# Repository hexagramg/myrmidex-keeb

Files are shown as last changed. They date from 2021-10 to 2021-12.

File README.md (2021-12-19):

# myrmidex-keeb
Myrmidex is split ergo hotswappable keyboard with two rotary encoders. 
Supports controllers with Pro-Micro layout, has footprints for power switch and battery. 

Myrmidex keyboard

In this repository you will find gerbers and schematics. Gerbers were exported with jlcpcb support in mind. Schematics were made in kicad. 

Right now qmk support is implemented, you can find it [here](https://github.com/hexagramg/qmk_firmware/tree/myrmidex/keyboards/myrmidex)

To build this keyboard you will need:
- SOD323 diodes of your choice x50
- PJ 320A trrs x2
- 0805 10k resistors x8
- 0805 10nf capacitors x4
- Kailh hotswap CPG151101S11 x48
- Alps ec11 encoders x2
- 48 mx compatible switches of your choice
- Pro-Micro x2
- Trrs cable

There are places for m2 standoffs, I used these:
- m2 4mm male-female standoff x16 (3mm is possible to fit) https://aliexpress.ru/item/4001271908929.html This one goes between pcb and bottom plate
- m2 3mm female-female standoff x16 https://aliexpress.ru/item/4001271908929.html This one between pcb and top plate
- m2 low profile screws x32 https://aliexpress.ru/item/32981714992.html Screw them tight on the bottom plate and somewhat loose on the top. 

Be careful on soldering left side, one diode on the bottom row is flipped. I will probably correct this in the next version, if there will be one.

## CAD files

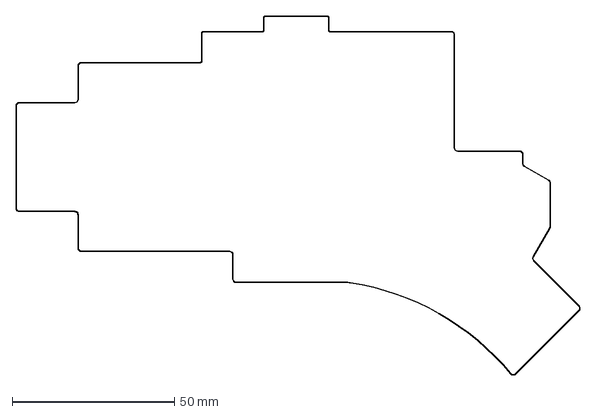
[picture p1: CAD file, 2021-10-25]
sketches/TopPlateEdge.dxf
173.5 x 110.4 mm

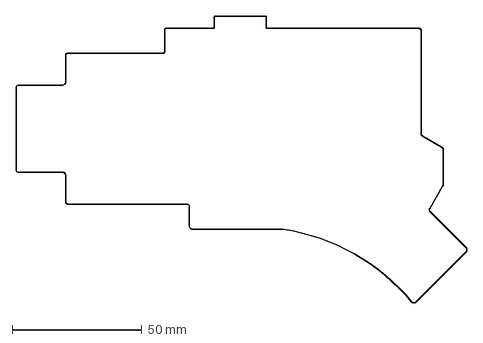
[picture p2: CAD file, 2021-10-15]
sketches/Pcbedge.dxf
173.5 x 110.4 mm

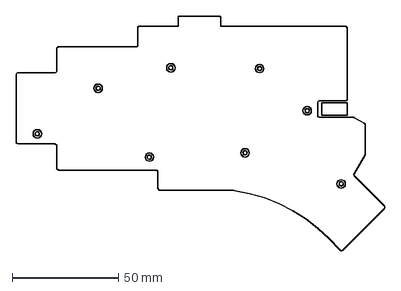
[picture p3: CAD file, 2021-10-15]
sketches/BottomPlateSketch.dxf
173.5 x 110.4 mm

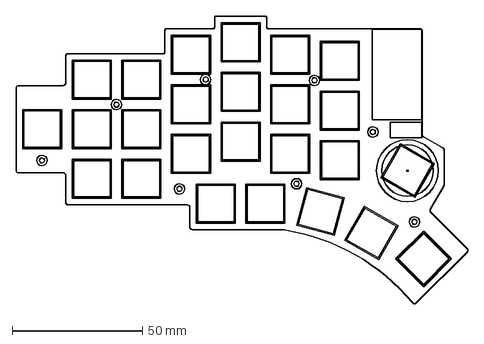
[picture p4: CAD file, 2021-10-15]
sketches/PcbSketch.dxf
173.5 x 110.4 mm

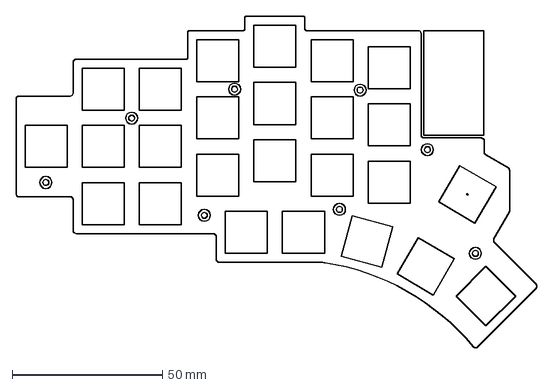
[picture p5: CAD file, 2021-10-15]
sketches/TopPlateSketch.dxf
173.5 x 110.4 mm

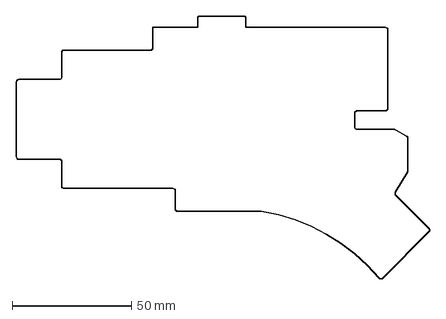
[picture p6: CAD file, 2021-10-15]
sketches/BottomPlateEdge.dxf
173.5 x 110.4 mm

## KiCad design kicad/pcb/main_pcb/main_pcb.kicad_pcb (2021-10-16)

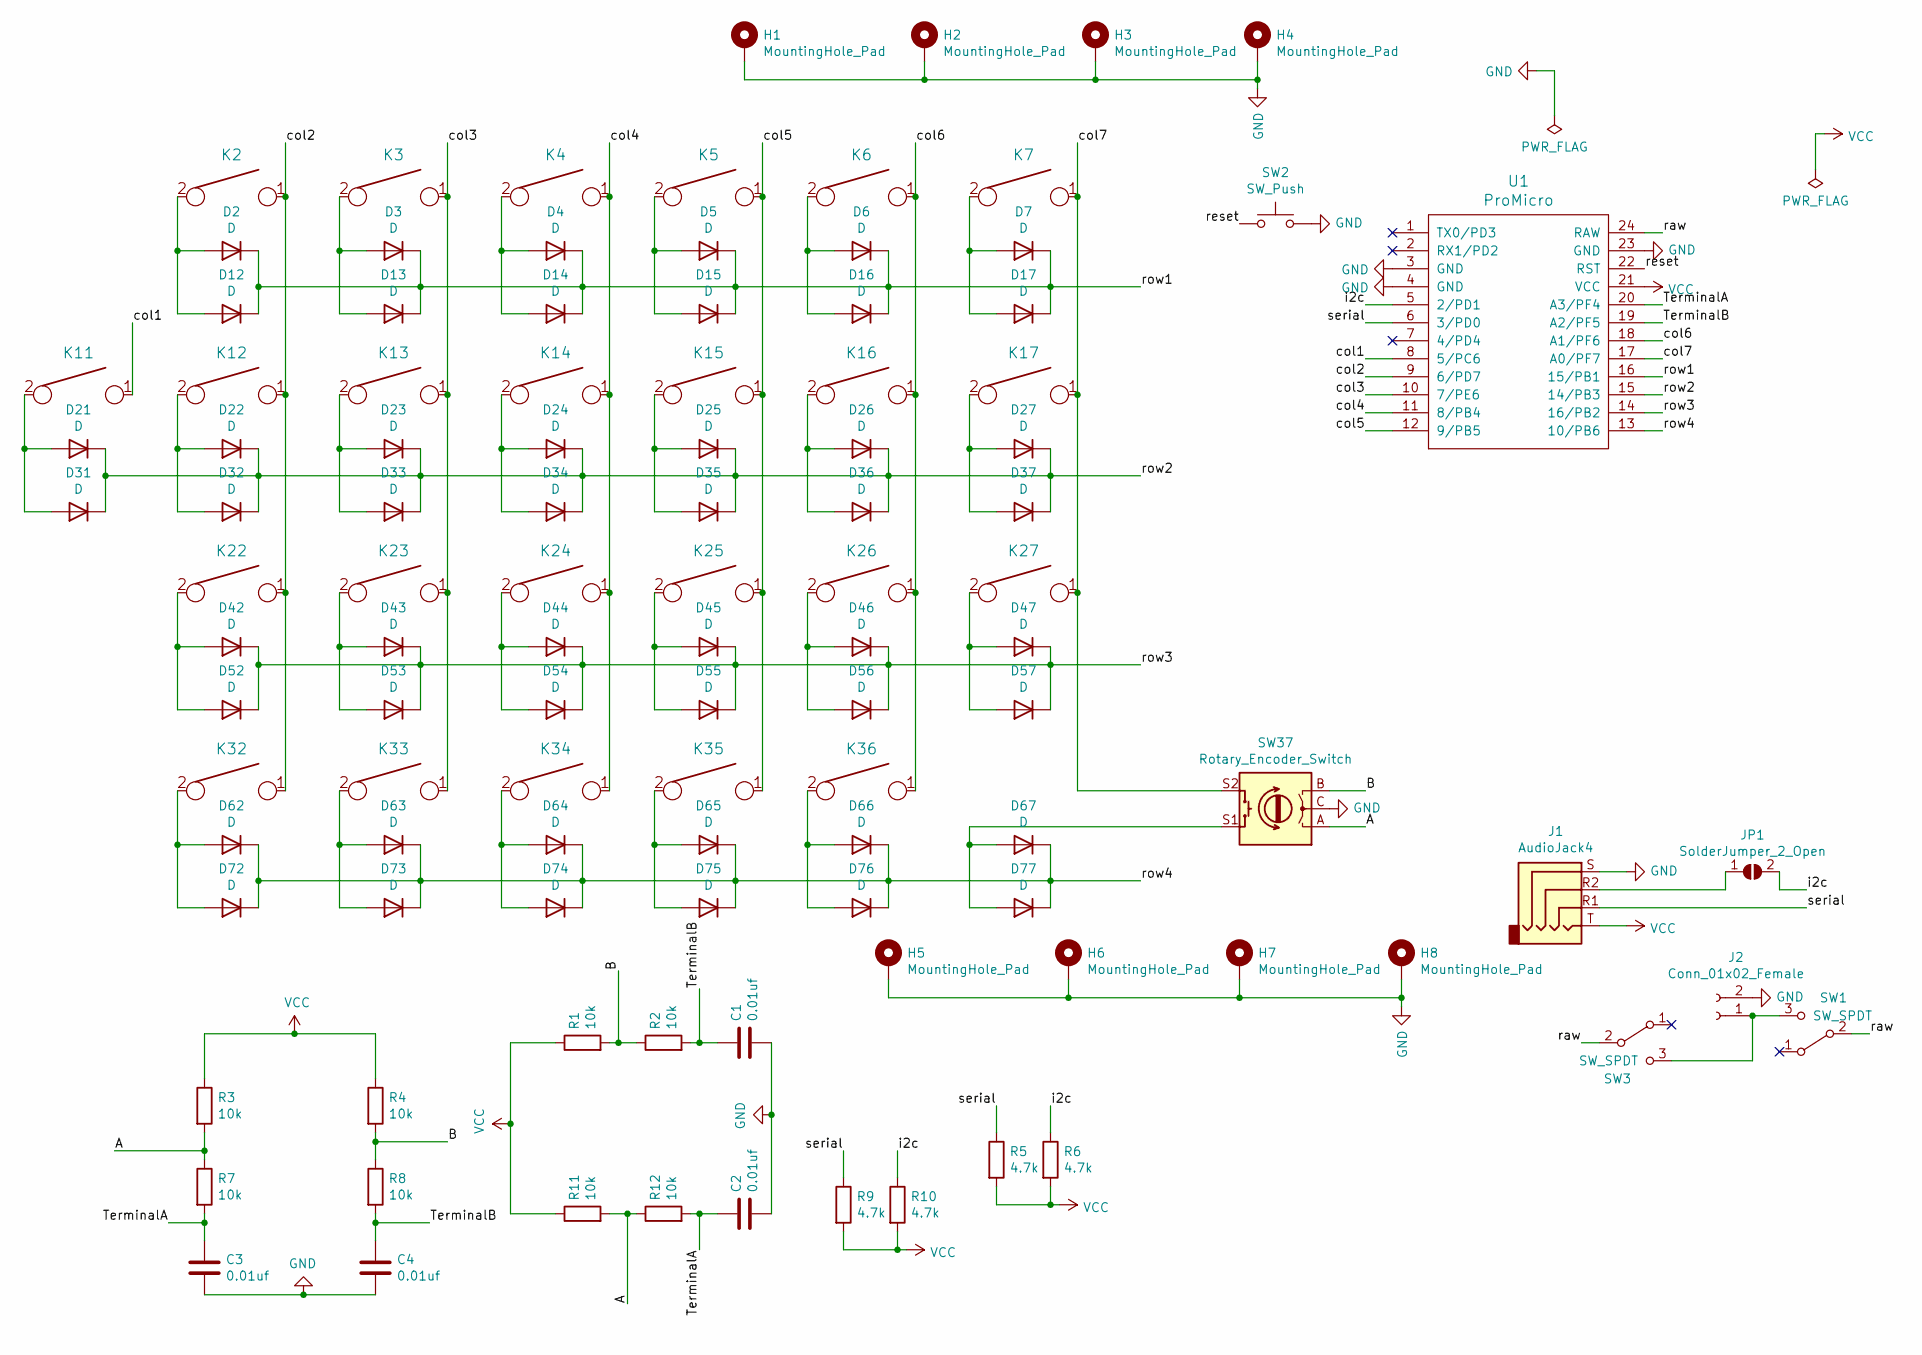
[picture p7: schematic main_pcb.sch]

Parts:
C1, C2, C3, C4: 0.01uf; C_0805_2012Metric_Pad1.18x1.45mm_HandSolder
D2, D3, D4, D5, D6, D7, D12, D13, D14, D15, D16, D17, D21, D22, D23, D24, D25, D26, D27, D31, D32, D33, D34, D35, D36, D37, D42, D43, D44, D45, D46, D47, D52, D53, D54, D55, D56, D57, D62, D63, D64, D65, D66, D67, D72, D73, D74, D75, D76, D77: D; D_0805_2012Metric_Pad1.15x1.40mm_HandSolder
H1, H2, H3, H4, H5, H6, H7, H8: MountingHole_Pad; MountingHole_2.2mm_M2_ISO14580_Pad
J1: AudioJack4; TRRS_PJ-320A_double
J2: Conn_01x02_Female; PinSocket_1x02_P2.54mm_Vertical
JP1: SolderJumper_2_Open; SolderJumper-2_P1.3mm_Open_Pad1.0x1.5mm
K2, K3, K4, K5, K6, K7, K11, K12, K13, K14, K15, K16, K17, K22, K23, K24, K25, K26, K27, K32, K33, K34, K35, K36: KEYSW-keyboard_parts; Kailh_socket_MX_optional_reversible_with_holes
R1, R2, R3, R4, R7, R8, R11, R12: 10k; R_0805_2012Metric_Pad1.20x1.40mm_HandSolder
R5, R6, R9, R10: 4.7k; R_0805_2012Metric_Pad1.20x1.40mm_HandSolder
SW1, SW3: SW_SPDT; SW_SPDT+H-MSK12C01_hor(7pin_SMD)
SW2: SW_Push; Switch_Reset_THT
SW37: Rotary_Encoder_Switch; RotaryEncoder_Alps_EC11E-Switch_Vertical_H20mm
U1: ProMicro; ProMicro_Dual

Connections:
/A: R3.2, R7.1, R11.2, R12.1, SW37.A
/B: R1.2, R2.1, R4.2, R8.1, SW37.B
/TerminalA: C2.1, C3.1, R7.2, R12.2, U1.20 (A3/PF4)
/TerminalB: C1.1, C4.1, R2.2, R8.2, U1.19 (A2/PF5)
/col1: K11.1, U1.8 (5/PC6)
/col2: K2.1, K12.1, K22.1, K32.1, U1.9 (6/PD7)
/col3: K3.1, K13.1, K23.1, K33.1, U1.10 (7/PE6)
/col4: K4.1, K14.1, K24.1, K34.1, U1.11 (8/PB4)
/col5: K5.1, K15.1, K25.1, K35.1, U1.12 (9/PB5)
/col6: K6.1, K16.1, K26.1, K36.1, U1.18 (A1/PF6)
/col7: K7.1, K17.1, K27.1, SW37.S2, U1.17 (A0/PF7)
/i2c: JP1.2 (B), R6.1, R10.1, U1.5 (2/PD1)
/raw: SW1.2 (B), SW3.2 (B), U1.24 (RAW)
/reset: SW2.1, U1.22 (RST)
/row1: D2.1 (K), D3.1 (K), D4.1 (K), D5.1 (K), D6.1 (K), D7.1 (K), D12.1 (K), D13.1 (K), D14.1 (K), D15.1 (K), D16.1 (K), D17.1 (K), U1.16 (15/PB1)
/row2: D21.1 (K), D22.1 (K), D23.1 (K), D24.1 (K), D25.1 (K), D26.1 (K), D27.1 (K), D31.1 (K), D32.1 (K), D33.1 (K), D34.1 (K), D35.1 (K), D36.1 (K), D37.1 (K), U1.15 (14/PB3)
/row3: D42.1 (K), D43.1 (K), D44.1 (K), D45.1 (K), D46.1 (K), D47.1 (K), D52.1 (K), D53.1 (K), D54.1 (K), D55.1 (K), D56.1 (K), D57.1 (K), U1.14 (16/PB2)
/row4: D62.1 (K), D63.1 (K), D64.1 (K), D65.1 (K), D66.1 (K), D67.1 (K), D72.1 (K), D73.1 (K), D74.1 (K), D75.1 (K), D76.1 (K), D77.1 (K), U1.13 (10/PB6)
/serial: J1.R1, R5.1, R9.1, U1.6 (3/PD0)
GND: C1.2, C2.2, C3.2, C4.2, H1.1, H2.1, H3.1, H4.1, H5.1, H6.1, H7.1, H8.1, J1.S, J2.2, SW2.2, SW37.C, U1.3 (GND), U1.4 (GND), U1.23 (GND)
unnamed: D2.2 (A), D12.2 (A), K2.2
unnamed: D3.2 (A), D13.2 (A), K3.2
unnamed: D4.2 (A), D14.2 (A), K4.2
unnamed: D5.2 (A), D15.2 (A), K5.2
unnamed: D6.2 (A), D16.2 (A), K6.2
unnamed: D7.2 (A), D17.2 (A), K7.2
unnamed: D21.2 (A), D31.2 (A), K11.2
unnamed: D22.2 (A), D32.2 (A), K12.2
unnamed: D23.2 (A), D33.2 (A), K13.2
unnamed: D24.2 (A), D34.2 (A), K14.2
unnamed: D25.2 (A), D35.2 (A), K15.2
unnamed: D26.2 (A), D36.2 (A), K16.2
unnamed: D27.2 (A), D37.2 (A), K17.2
unnamed: D42.2 (A), D52.2 (A), K22.2
unnamed: D43.2 (A), D53.2 (A), K23.2
unnamed: D44.2 (A), D54.2 (A), K24.2
unnamed: D45.2 (A), D55.2 (A), K25.2
unnamed: D46.2 (A), D56.2 (A), K26.2
unnamed: D47.2 (A), D57.2 (A), K27.2
unnamed: D62.2 (A), D72.2 (A), K32.2
unnamed: D63.2 (A), D73.2 (A), K33.2
unnamed: D64.2 (A), D74.2 (A), K34.2
unnamed: D65.2 (A), D75.2 (A), K35.2
unnamed: D66.2 (A), D76.2 (A), K36.2
unnamed: D67.2 (A), D77.2 (A), SW37.S1
unnamed: J1.R2, JP1.1 (A)
unnamed: J2.1, SW1.3 (C), SW3.3 (C)
VCC: J1.T, R1.1, R3.1, R4.1, R5.2, R6.2, R9.2, R10.2, R11.1, U1.21 (VCC)

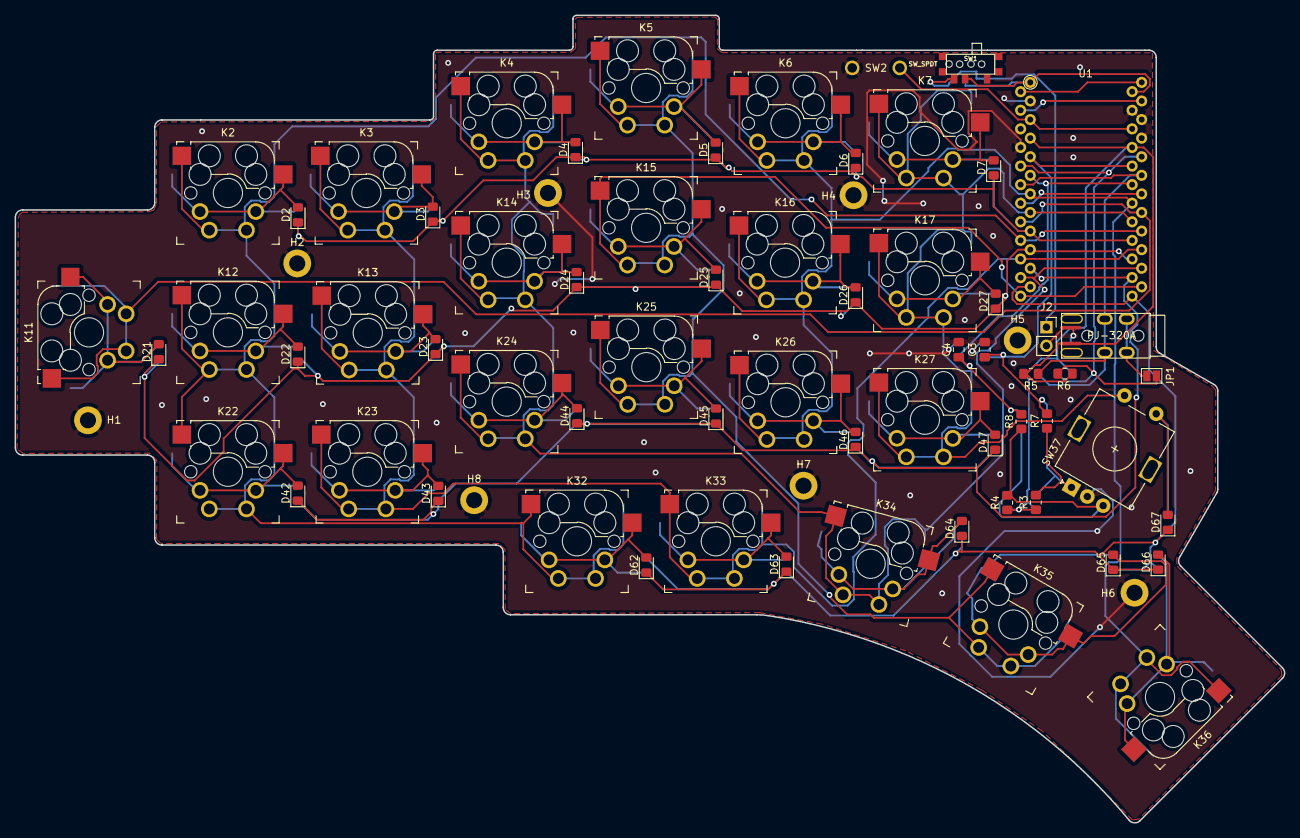
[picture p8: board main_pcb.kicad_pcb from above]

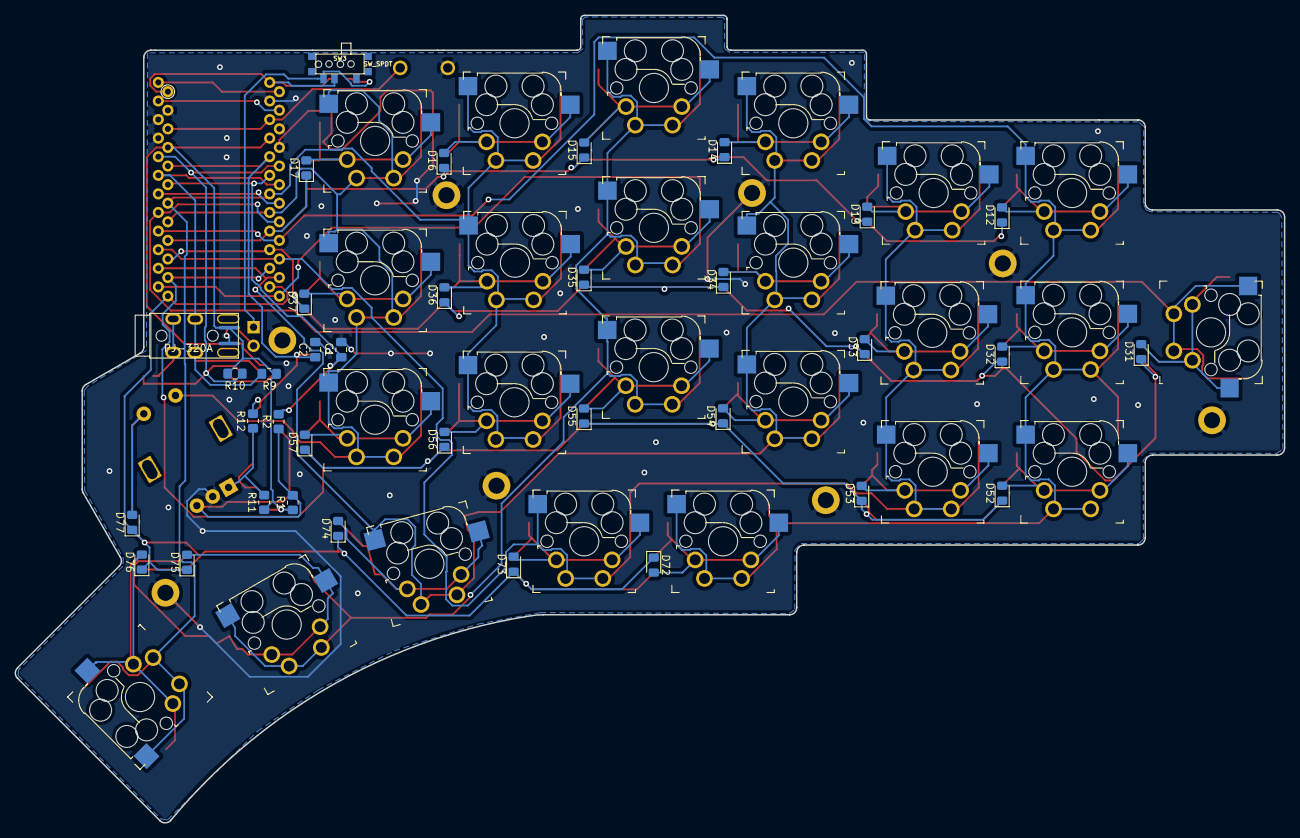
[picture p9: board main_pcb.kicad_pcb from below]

Board: 2 copper layers, 173.5 x 110.4 mm, 106 parts (34 on the bottom side), 48 nets.

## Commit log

2021-10-15 Sketches for all the future planes
    [BottomPlateEdge.dxf, BottomPlateSketch.dxf, PcbSketch.dxf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]
2021-10-16 Main pcb done
    [main_pcb.kicad_pcb, main_pcb.sch]
2021-10-25 gerbers added
    [TopPlateEdge.dxf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]
